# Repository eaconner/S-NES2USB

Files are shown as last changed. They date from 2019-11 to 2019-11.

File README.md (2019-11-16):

# (S)NES2USB

Upgrade your NES or SNES controller to USB. Can be put inside the controller, or build real NES/SNES ports onto your computer. Works with standard controllers (original, Max, dogbone, Advantage, etc), does not work with peripherals (Zapper, FourScore, etc).
[OSHPark](https://oshpark.com/shared_projects/MCnz0W9w)  |  [DigiKey BOM](https://www.digikey.com/BOM/Create/CreateSharedBom?bomId=7739089)







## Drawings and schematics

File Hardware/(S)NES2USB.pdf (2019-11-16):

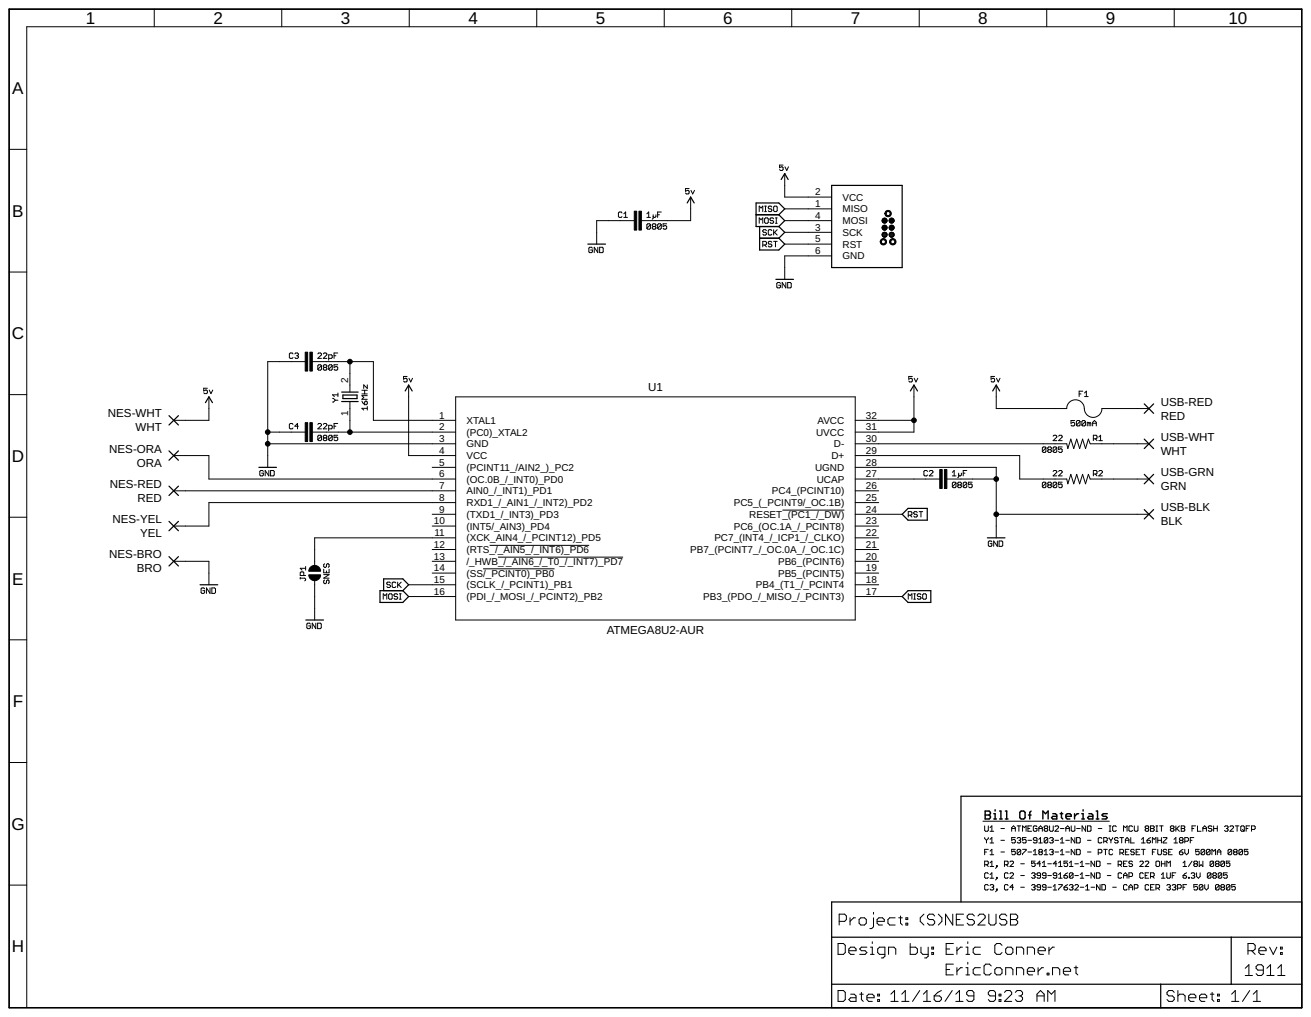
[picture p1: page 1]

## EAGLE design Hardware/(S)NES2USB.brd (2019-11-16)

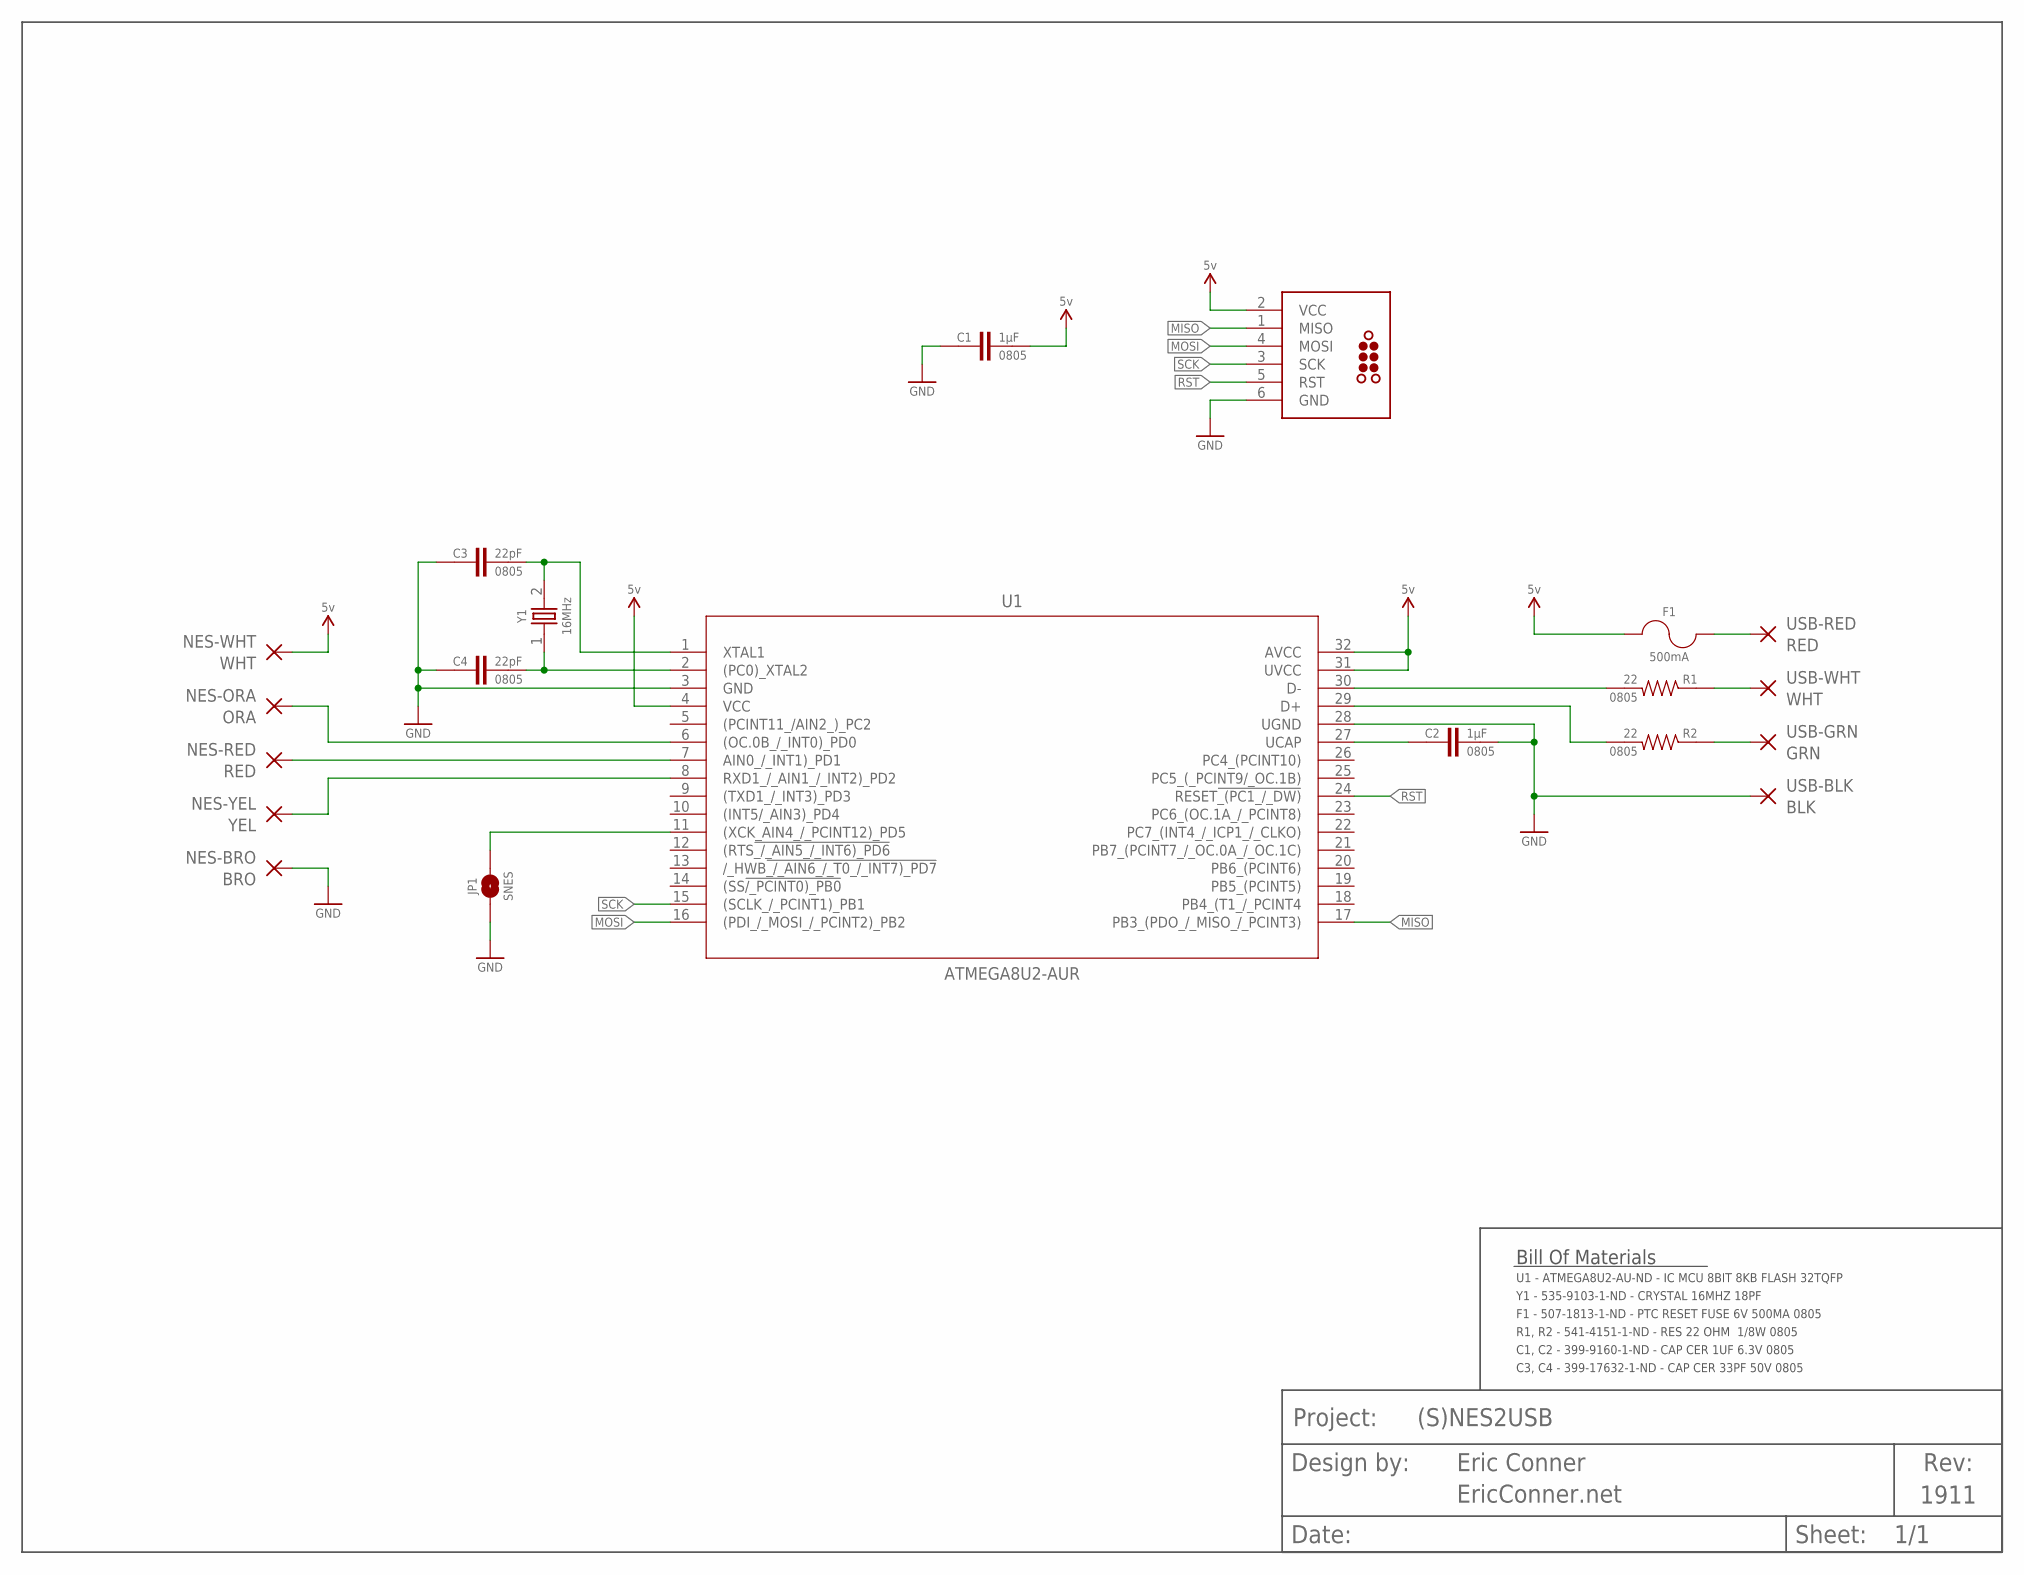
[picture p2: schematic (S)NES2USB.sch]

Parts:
BORDER1: BORDER_LETTER-MINIMAL; MINIMAL_LOGO
C1, C2: 1µF; 0805
C3, C4: 22pF; 0805
F1: 500mA; 0805
J1: TC2030
JP1: SNES; SMT-JUMPER_2_NO_SILK
NES-BRO: BRO; SMD1,27-2,54
NES-ORA: ORA; SMD1,27-2,54
NES-RED: RED; SMD1,27-2,54
NES-WHT: WHT; SMD1,27-2,54
NES-YEL: YEL; SMD1,27-2,54
R1, R2: 22; 0805
U1: ATMEGA8U2-AUR; TQFP32
USB-BLK: BLK; SMD1,27-2,54
USB-GRN: GRN; SMD1,27-2,54
USB-RED: RED; SMD1,27-2,54
USB-WHT: WHT; SMD1,27-2,54
Y1: 16MHz; XTAL500X320X130N

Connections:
3V3: C2.1, U1.27 (UCAP)
CLOCK: NES-RED.1, U1.7 (AIN0_/_INT1)_PD1)
D+: R2.2, U1.29 (D+)
D-: R1.2, U1.30 (D-)
DATA: NES-YEL.1, U1.8 (RXD1_/_AIN1_/_INT2)_PD2)
GND: C1.1, C2.2, C3.1, C4.1, J1.6 (GND), JP1.1, NES-BRO.1, U1.3 (GND), U1.28 (UGND), USB-BLK.1
LATCH: NES-ORA.1, U1.6 ((OC.0B_/_INT0)_PD0)
MISO: J1.1 (MISO), U1.17 (PB3_(PDO_/_MISO_/_PCINT3))
MOSI: J1.4 (MOSI), U1.16 ((PDI_/_MOSI_/_PCINT2)_PB2)
RST: J1.5 (RST), U1.24 (RESET!_(PC1_/_DW))
SCK: J1.3 (SCK), U1.15 ((SCLK_/_PCINT1)_PB1)
SNES: JP1.2, U1.11 ((XCK_AIN4_/_PCINT12)_PD5)
USB_5V: F1.1, USB-RED.1
USB_D+: R2.1, USB-GRN.1
USB_D-: R1.1, USB-WHT.1
VCC: C1.2, F1.2, J1.2 (VCC), NES-WHT.1, U1.4 (VCC), U1.31 (UVCC), U1.32 (AVCC)
XTAL1: C4.2, U1.2 ((PC0)_XTAL2), Y1.1
XTAL2: C3.2, U1.1 (XTAL1), Y1.2

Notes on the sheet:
Bill Of Materials
U1 - ATMEGA8U2-AU-ND - IC MCU 8BIT 8KB FLASH 32TQFP
Y1 - 535-9103-1-ND - CRYSTAL 16MHZ 18PF
F1 - 507-1813-1-ND - PTC RESET FUSE 6V 500MA 0805
R1, R2 - 541-4151-1-ND - RES 22 OHM 1/8W 0805
C1, C2 - 399-9160-1-ND - CAP CER 1UF 6.3V 0805
C3, C4 - 399-17632-1-ND - CAP CER 33PF 50V 0805

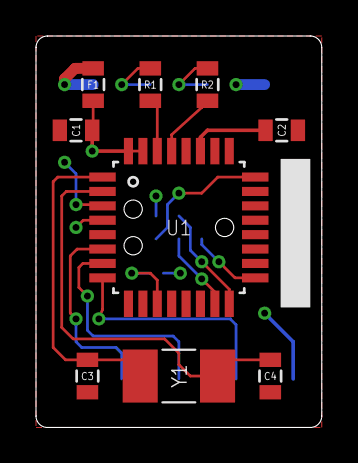
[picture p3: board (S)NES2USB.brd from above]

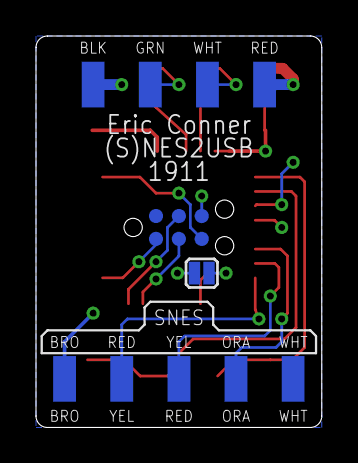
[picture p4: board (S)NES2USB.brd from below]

Board: 2 copper layers, 15.9 x 21.7 mm, 21 parts (12 on the bottom side), 18 nets.

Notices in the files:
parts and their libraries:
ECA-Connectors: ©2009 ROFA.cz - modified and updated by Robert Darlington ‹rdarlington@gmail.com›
